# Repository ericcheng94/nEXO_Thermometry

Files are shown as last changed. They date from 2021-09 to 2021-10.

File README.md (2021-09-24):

# nNEXO_Microcontroller_Temp
Using Teensy 4.1 and Arduino Mega to collect temperatures using PT100's and thermocouples

Current TODO:
- Revise millis() timing system
- Fix NativeEthernet locking issue
- Prevent LCD burn in

Future feature adds:
- Utilize ILI9341 touch feature for interactive display

Schematic of PCB
thermo_schema

PCBnew
pcb

PCB Version 1  
https://oshpark.com/shared_projects/pfnhz9rr

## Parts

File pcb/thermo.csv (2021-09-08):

Reference | Quantity | Value | Footprint | Datasheet
0.1uF1 | 1 | C1 | Capacitor_THT:C_Disc_D3.0mm_W1.6mm_P2.50mm | Digikey BC1084CT-ND
ADC1 ADC2 ADC3 ADC4 ADC5 | 5 | PT100 | Thermometry:MAX31865
ADC6 | 1 | thermocouple1 | Thermometry:MAX31856
ADC7 | 1 | thermocouple2 | Thermometry:MAX31856
CP1 | 1 | 47uF | Capacitor_THT:CP_Radial_D5.0mm_P2.00mm | 2368-VHT47M25-ND
F1 | 1 | 1A | Thermometry:thermo_fuse | https://www.digikey.com/en/products/detail/littelfuse-inc/0154001-DRTL/2520456
ILI9341TFT1 ILI9341TFT2 | 2 | Conn_01x14 | Thermometry:ILI9341_2x7_connector | ~
ILI9341TFT3 | 1 | Conn_01x14 | Thermometry:ILI9341_1x14_connector | ~
J1 | 1 | DB15_Female | Thermometry:D15_Female_Horizontal | ~
J2 | 1 | Barrel_Jack | Connector_BarrelJack:BarrelJack_Horizontal | https://www.digikey.com/en/products/detail/cui-devices/PJ-002A/96962
MCU1 | 1 | Teensy4.1 | Thermometry:Teensy41
R1 R2 R3 R4 R5 R6 R7 R8 R9 R10 R11 R12 | 12 | 22 | Resistor_SMD:R_0805_2012Metric_Pad1.20x1.40mm_HandSolder | ~
R13 | 1 | 0 | Resistor_SMD:R_0805_2012Metric_Pad1.20x1.40mm_HandSolder | ~
Teensy_Ethernet1 | 1 | RJ45_LED | Connector_RJ:RJ45_Cetus_J1B1211CCD_Horizontal | ~
U1 | 1 | BME280 | Thermometry:BME280

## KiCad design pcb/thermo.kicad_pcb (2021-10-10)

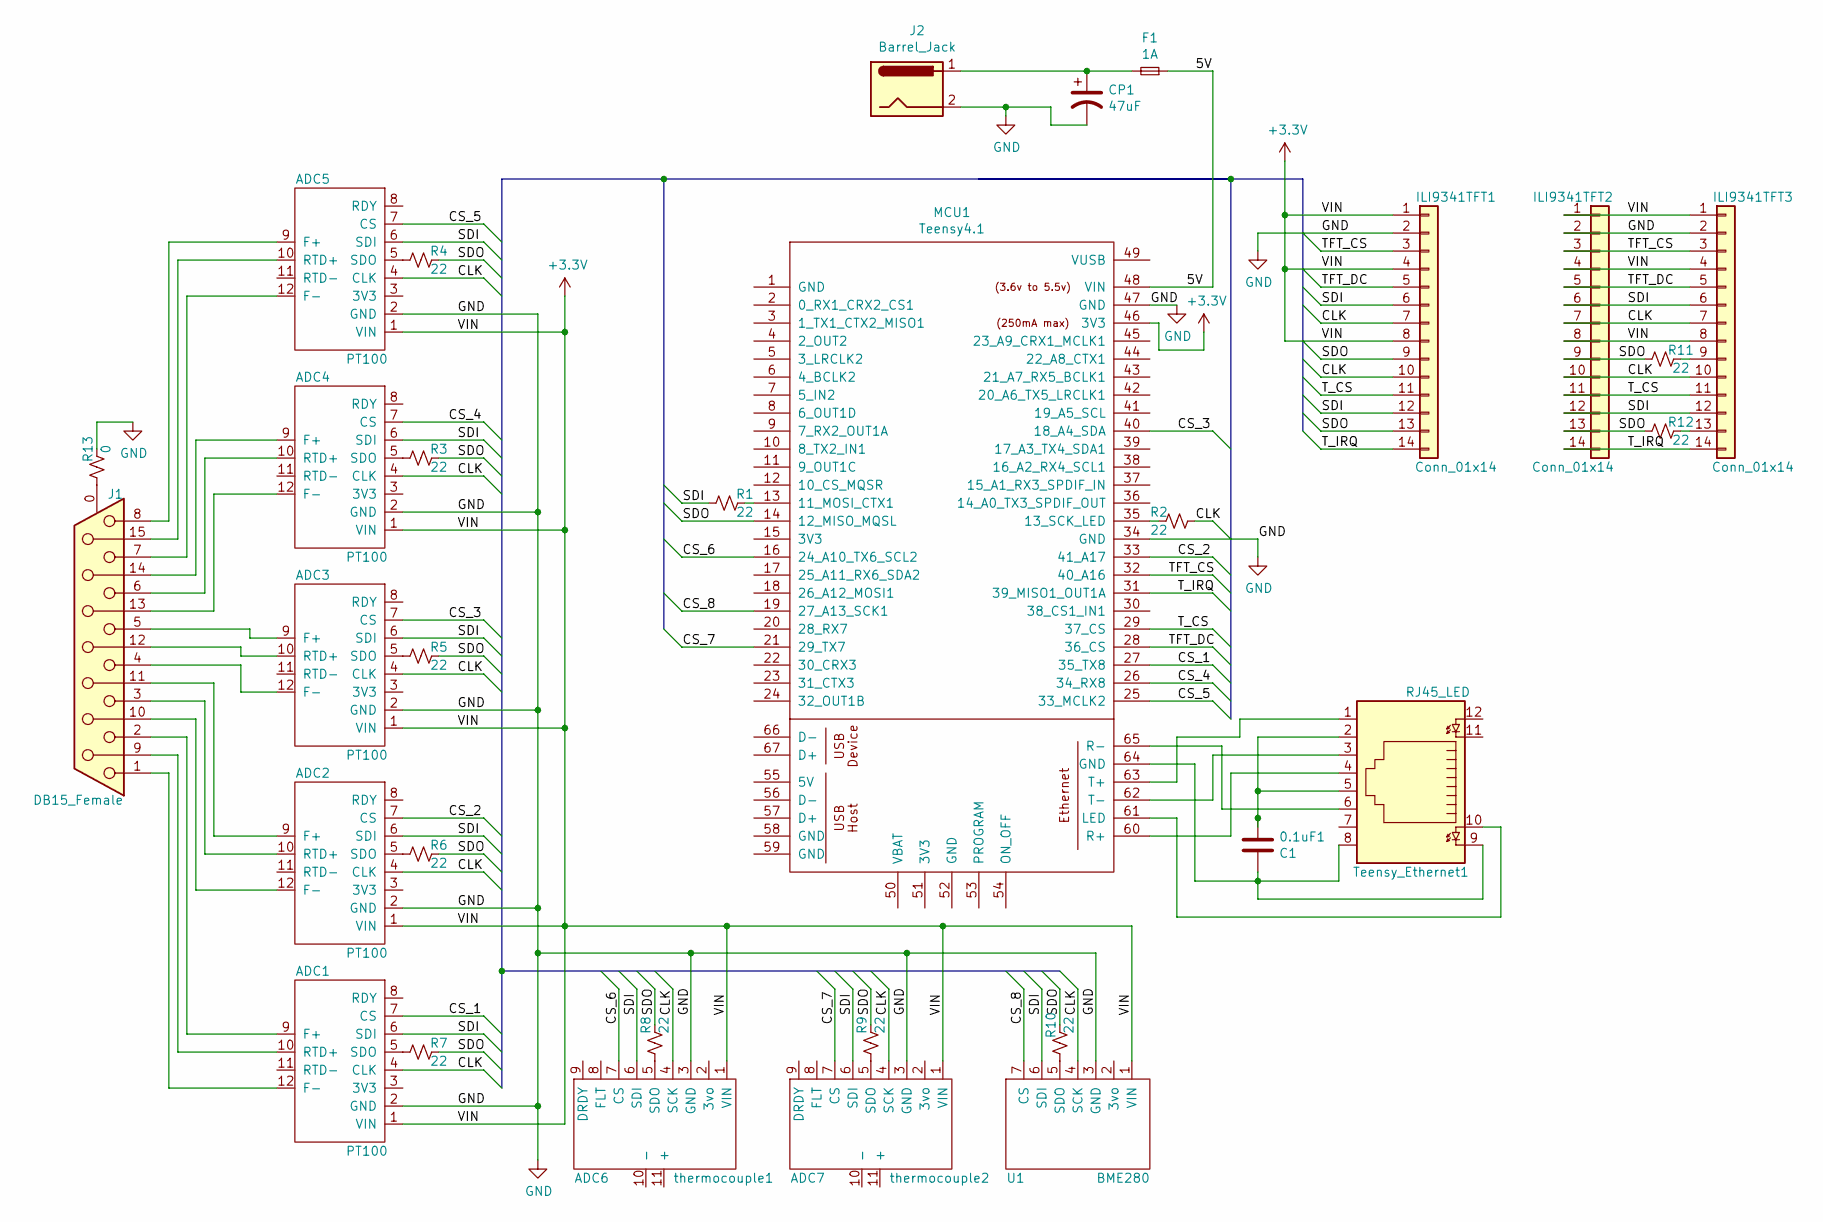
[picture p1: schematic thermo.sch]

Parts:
0.1uF1: C1; C_Disc_D3.0mm_W1.6mm_P2.50mm
ADC1, ADC2, ADC3, ADC4, ADC5: PT100; MAX31865
ADC6: thermocouple1; MAX31856
ADC7: thermocouple2; MAX31856
CP1: 47uF; CP_Radial_D5.0mm_P2.00mm
F1: 1A; thermo_fuse
ILI9341TFT1, ILI9341TFT2: Conn_01x14; ILI9341_2x7_connector
ILI9341TFT3: Conn_01x14; ILI9341_1x14_connector
J1: DB15_Female; D15_Female_Horizontal
J2: Barrel_Jack; BarrelJack_Horizontal
MCU1: Teensy4.1; Teensy41
R1, R2, R3, R4, R5, R6, R7, R8, R9, R10, R11, R12: 22; R_0805_2012Metric_Pad1.20x1.40mm_HandSolder
R13: 0; R_0805_2012Metric_Pad1.20x1.40mm_HandSolder
Teensy_Ethernet1: RJ45_LED; RJ45_Cetus_J1B1211CCD_Horizontal
U1: BME280

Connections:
+3V3: ADC1.1 (VIN), ADC2.1 (VIN), ADC3.1 (VIN), ADC4.1 (VIN), ADC5.1 (VIN), ADC6.1 (VIN), ADC7.1 (VIN), ILI9341TFT1.1, ILI9341TFT1.4, ILI9341TFT1.8, ILI9341TFT2.1, ILI9341TFT2.4, ILI9341TFT2.8, ILI9341TFT3.1, ILI9341TFT3.4, ILI9341TFT3.8, MCU1.46 (3V3), U1.1 (VIN)
/5V: F1.1, MCU1.48 (VIN)
/CLK: ADC1.4 (CLK), ADC2.4 (CLK), ADC3.4 (CLK), ADC4.4 (CLK), ADC5.4 (CLK), ADC6.4 (SCK), ADC7.4 (SCK), ILI9341TFT1.7, ILI9341TFT1.10, ILI9341TFT2.7, ILI9341TFT2.10, ILI9341TFT3.7, ILI9341TFT3.10, R2.1, U1.4 (SCK)
/CS_1: ADC1.7 (CS), MCU1.27 (35_TX8)
/CS_2: ADC2.7 (CS), MCU1.33 (41_A17)
/CS_3: ADC3.7 (CS), MCU1.40 (18_A4_SDA)
/CS_4: ADC4.7 (CS), MCU1.26 (34_RX8)
/CS_5: ADC5.7 (CS), MCU1.25 (33_MCLK2)
/CS_6: ADC6.7 (CS), MCU1.16 (24_A10_TX6_SCL2)
/CS_7: ADC7.7 (CS), MCU1.21 (29_TX7)
/CS_8: MCU1.19 (27_A13_SCK1), U1.7 (CS)
/SDI: ADC1.6 (SDI), ADC2.6 (SDI), ADC3.6 (SDI), ADC4.6 (SDI), ADC5.6 (SDI), ADC6.6 (SDI), ADC7.6 (SDI), ILI9341TFT1.6, ILI9341TFT1.12, ILI9341TFT2.6, ILI9341TFT2.12, ILI9341TFT3.6, ILI9341TFT3.12, R1.2, U1.6 (SDI)
/SDO: ILI9341TFT1.9, ILI9341TFT1.13, ILI9341TFT2.9, ILI9341TFT2.13, MCU1.14 (12_MISO_MQSL), R3.1, R4.1, R5.1, R6.1, R7.1, R8.1, R9.1, R10.1, R11.2, R12.2
/TFT_CS: ILI9341TFT1.3, ILI9341TFT2.3, ILI9341TFT3.3, MCU1.32 (40_A16)
/TFT_DC: ILI9341TFT1.5, ILI9341TFT2.5, ILI9341TFT3.5, MCU1.28 (36_CS)
/T_CS: ILI9341TFT1.11, ILI9341TFT2.11, ILI9341TFT3.11, MCU1.29 (37_CS)
/T_IRQ: ILI9341TFT1.14, ILI9341TFT2.14, ILI9341TFT3.14, MCU1.31 (39_MISO1_OUT1A)
GND: ADC1.2 (GND), ADC2.2 (GND), ADC3.2 (GND), ADC4.2 (GND), ADC5.2 (GND), ADC6.3 (GND), ADC7.3 (GND), CP1.2, ILI9341TFT1.2, ILI9341TFT2.2, ILI9341TFT3.2, J2.2, MCU1.34 (GND), MCU1.47 (GND), R13.1, U1.3 (GND)
unnamed: 0.1uF1.1, Teensy_Ethernet1.2, Teensy_Ethernet1.5
unnamed: 0.1uF1.2, MCU1.64 (GND), Teensy_Ethernet1.8, Teensy_Ethernet1.9
unnamed: ADC1.5 (SDO), R7.2
unnamed: ADC1.9 (F+), J1.2
unnamed: ADC1.10 (RTD+), J1.9
unnamed: ADC1.12 (F-), J1.1
unnamed: ADC2.5 (SDO), R6.2
unnamed: ADC2.9 (F+), J1.11 (P111)
unnamed: ADC2.10 (RTD+), J1.3
unnamed: ADC2.12 (F-), J1.10
unnamed: ADC3.5 (SDO), R5.2
unnamed: ADC3.9 (F+), J1.5
unnamed: ADC3.10 (RTD+), J1.12
unnamed: ADC3.12 (F-), J1.4
unnamed: ADC4.5 (SDO), R3.2
unnamed: ADC4.9 (F+), J1.14
unnamed: ADC4.10 (RTD+), J1.6
unnamed: ADC4.12 (F-), J1.13
unnamed: ADC5.5 (SDO), R4.2
unnamed: ADC5.9 (F+), J1.8
unnamed: ADC5.10 (RTD+), J1.15
unnamed: ADC5.12 (F-), J1.7
unnamed: ADC6.5 (SDO), R8.2
unnamed: ADC7.5 (SDO), R9.2
unnamed: CP1.1, F1.2, J2.1
unnamed: ILI9341TFT3.9, R11.1
unnamed: ILI9341TFT3.13, R12.1
unnamed: J1.0 (PAD), R13.2
unnamed: MCU1.13 (11_MOSI_CTX1), R1.1
unnamed: MCU1.35 (13_SCK_LED), R2.2
unnamed: MCU1.60 (R+), Teensy_Ethernet1.4
unnamed: MCU1.61 (LED), Teensy_Ethernet1.10
unnamed: MCU1.62 (T-), Teensy_Ethernet1.3
unnamed: MCU1.63 (T+), Teensy_Ethernet1.1
unnamed: MCU1.65 (R-), Teensy_Ethernet1.6
unnamed: R10.2, U1.5 (SDO)

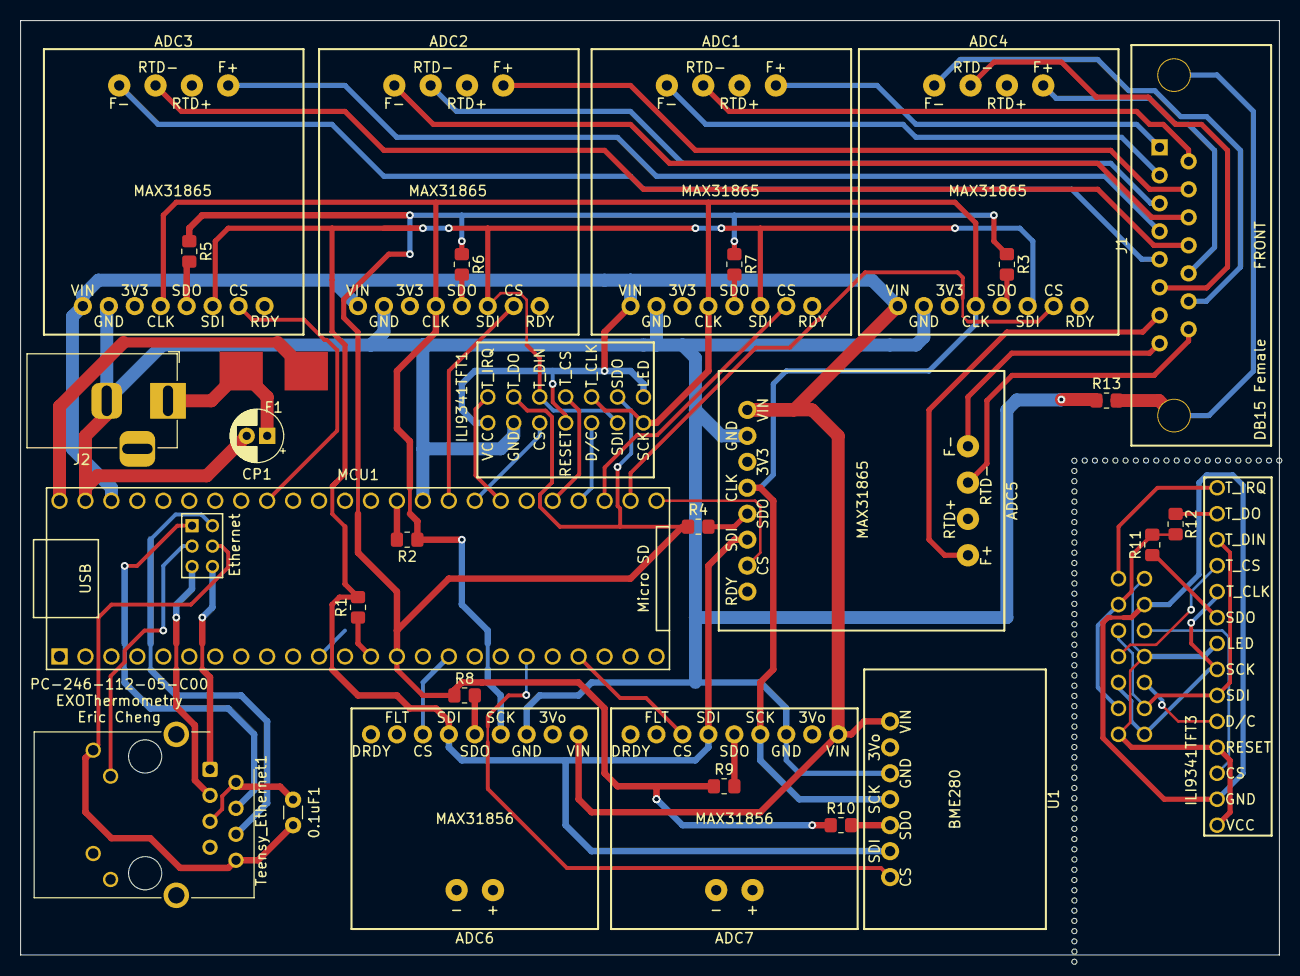
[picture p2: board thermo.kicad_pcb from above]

Board: 2 copper layers, 123.2 x 91.4 mm, 31 parts (1 on the bottom side), 54 nets.

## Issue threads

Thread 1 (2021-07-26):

Ambiguous declare

bungernut, 2021-07-26:
https://github.com/ericcheng94/nNEXO_Microcontroller_Temp/blob/5b1cc3159d358c7eaec6f1060fe57ec7ec3c33e6/nEXO_Teensy.ino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

you should use uint32_t to remove any ambiguity in size. It may not be an issue in the Arduino environment but it's a good habit to use them since different compilers could have different lengths. Also less typing so win-win.

Closed 2021-09-10.

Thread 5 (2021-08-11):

NativeEthernet.begin is locking

bungernut, 2021-08-11:
It turns out that begin method in NativeEthernet is going to hang the system if no ethernet cable is connected.
https://github.com/vjmuzik/NativeEthernet/blob/fe82aa7cab344760346bda5d0da031a4adeff2e2/src/NativeEthernet.cpp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

No obvious fix exists as far as I know, but it's discussed here:
https://forum.pjrc.com/threads/65653-non-blocking-Ethernet-begin()-with-cable-disconnected-amp-static-IP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

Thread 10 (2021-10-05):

RTD+ and RTD- got reversed from SCH to PCB

bungernut, 2021-10-05:
The 3 wire RTD should connect to RTD+ F+ and F-, this was correct on the SCH, but it is wrong on the PCB.

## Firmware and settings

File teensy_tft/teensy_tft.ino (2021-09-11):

#include <Adafruit_MAX31865.h>
#include <Adafruit_MAX31856.h>
#include <Adafruit_BME280.h>
#include <Wire.h>
#include <SPI.h>
#include "ILI9341_t3.h"
#include <NativeEthernet.h>
#include <Arduino.h>
#include <ArduinoRS485.h> // ArduinoModbus depends on the ArduinoRS485 library
#include <ArduinoModbus.h>

Adafruit_MAX31865 rtd01 = Adafruit_MAX31865(35);
Adafruit_MAX31865 rtd02 = Adafruit_MAX31865(41);
// Adafruit_MAX31865 rtd03 = Adafruit_MAX31865(18);
// Adafruit_MAX31865 rtd04 = Adafruit_MAX31865(34);
// Adafruit_MAX31865 rtd05 = Adafruit_MAX31865(33);
Adafruit_MAX31856 tcp01 = Adafruit_MAX31856(24);
// Adafruit_MAX31856 tcp02 = Adafruit_MAX31856(29);
Adafruit_BME280 bme(27); // hardware SPI

#define VERSION "nEXO Thermometry v1.1"
#define TFT_DC 36
#define TFT_CS 40
#define T_CS 37
#define T_IRQ 39
ILI9341_t3 tft = ILI9341_t3(TFT_CS, TFT_DC);

// The value of the Rref resistor. Use 430.0 for PT100 and 4300.0 for PT1000
#define RREF      430.0
// The 'nominal' 0-degrees-C resistance of the sensor
// 100.0 for PT100, 1000.0 for PT1000
#define RNOMINAL  100.0

// Enter a MAC address for your controller below.
byte mac[] = {0xDE, 0xAD, 0xBE, 0xEF, 0xFE, 0xED};
// The IP address will be dependent on your local network:
IPAddress ip(192, 168, 0, 242);

EthernetServer ethServer(502);
ModbusTCPServer modbusTCPServer;

uint32_t currentMillis;
uint32_t pollModbusMillis;
uint32_t updateSensorsMillis;
uint32_t updateClientMillis;
uint32_t updateSerialMillis;
uint32_t updateDisplayMillis;
// unsigned int  heartbeat;

// Global variables to make current sensor temps available to every function
float rtd01temp;
float rtd02temp;
float rtd03temp;
float rtd04temp;
float rtd05temp;
float tcp01temp;
float tcp02temp;
float bmeTemp;

//Modbus holding register address mapping
const int rtd01_reg = 0x00;
const int rtd02_reg = 0x01;
const int rtd03_reg = 0x02;
const int rtd04_reg = 0x03;
const int rtd05_reg = 0x04;
const int tcp01_reg1 = 0x05;
const int tcp01_reg2 = 0x06;
const int tcp02_reg1 = 0x07;
const int tcp02_reg2 = 0x08;
const int bme_reg1 = 0x09;
const int bme_reg2 = 0x010;
// const int tick_tock = 0x11;

void setup() {
  Serial.begin(115200);
//  while (!Serial) {
//    ; // wait for serial port to connect. Needed for native USB port only
//  }
  Serial.println(VERSION);
  rtd01.begin(MAX31865_3WIRE);  // set to 2WIRE or 4WIRE as necessary
  rtd02.begin(MAX31865_3WIRE);  // set to 2WIRE or 4WIRE as necessary
//  rtd03.begin(MAX31865_3WIRE);  // set to 2WIRE or 4WIRE as necessary
//  rtd04.begin(MAX31865_3WIRE);  // set to 2WIRE or 4WIRE as necessary
//  rtd05.begin(MAX31865_3WIRE);  // set to 2WIRE or 4WIRE as necessary
  tcp01.begin();
  tcp01.setThermocoupleType(MAX31856_TCTYPE_T);
//  tcp02.begin();
//  tcp02.setThermocoupleType(MAX31856_TCTYPE_T);
  tft.begin();

  Ethernet.begin(mac, ip);
  // Check for Ethernet hardware present
  if (Ethernet.hardwareStatus() == EthernetNoHardware) {
    Serial.println("Ethernet shield was not found.  Sorry, can't run without hardware. :(");
    while (true) {
      delay(1); // do nothing, no point running without Ethernet hardware
    }
  }
  // Keeps displaying error despite having thernet connection, commented out for now
  // if (Ethernet.linkStatus() == LinkOFF) {
  //   Serial.println("Ethernet cable is not connected.");
  // }

  // Start the server
  ethServer.begin();

  // start the Modbus TCP server
  if (!modbusTCPServer.begin()) {
    Serial.println("Failed to start Modbus TCP Server!");
    while (1);
  }

  // initialize BME280 sensor
  bme.begin();
//  if (!bme.begin()) {
//    Serial.println("Could not find a valid BME280 sensor, check wiring!");
//    while (1);
//  }

  // configure 12 holding registers at address 0x00
  modbusTCPServer.configureHoldingRegisters(0x00, 12);

  // Setup ILI9341 TFT LCD
  tft.fillScreen(ILI9341_BLACK);
  tft.setTextColor(ILI9341_WHITE);
  tft.setTextSize(3);
  tft.setRotation(3);
  tft.setCursor(10, 10);
  tft.println(VERSION);
  tft.fillScreen(ILI9341_BLACK);
}

void loop() {
  EthernetClient client = ethServer.available();
  // listen for incoming clients
  if (client) {
    Serial.println("Client Connected");
    modbusTCPServer.accept(client);

    while (client.connected()) {
      currentMillis = millis();

      if (currentMillis - pollModbusMillis > 1000) {
        // poll for Modbus TCP requests, while client connected
        modbusTCPServer.poll();
        pollModbusMillis = currentMillis;

//         if (heartbeat > 65000) {
//           heartbeat = 1;
//         } else if (heartbeat % 2 == 1) {
//           modbusTCPServer.holdingRegisterWrite(tick_tock, 1);
//           heartbeat = 0;
//         } else {
//           modbusTCPServer.holdingRegisterWrite(tick_tock, 0);
//           heartbeat = 1;
//         }
      }

      if (currentMillis - updateSensorsMillis > 250) {
        rtd01temp = rtd01.temperature(RNOMINAL, RREF);
        rtd02temp = rtd02.temperature(RNOMINAL, RREF);
//        rtd03temp = rtd03.temperature(RNOMINAL, RREF);
//        rtd04temp = rtd04.temperature(RNOMINAL, RREF);
//        rtd05temp = rtd05.temperature(RNOMINAL, RREF);
        tcp01temp = tcp01.readThermocoupleTemperature();
//        tcp02temp = tcp02.readThermocoupleTemperature();
        bmeTemp = bme.readTemperature();

        // Change Celsius to Kelvin
        rtd01temp += 273.15;
        rtd02temp += 273.15;
        rtd03temp += 273.15;
        rtd04temp += 273.15;
        rtd05temp += 273.15;
        tcp01temp += 273.15;
        tcp02temp += 273.15;
        bmeTemp += 273.15;

        updateSensorsMillis = currentMillis;
      }

      if (currentMillis - updateClientMillis > 1000) {
        updateClient(tcp01temp, bmeTemp);
//        updateClient(tcp01temp, tcp02temp);
        updateClientMillis = currentMillis;
      }

      if (currentMillis - updateSerialMillis > 2000) {
        updateSerial(rtd01temp, rtd02temp, tcp01temp, bmeTemp);
//        updateSerial(rtd01temp, rtd02temp, rtd03temp, rtd04temp, rtd05temp, tcp01temp, tcp02temp, bmeTemp);
        updateSerialMillis = currentMillis;
      }

      if (currentMillis - updateDisplayMillis > 1000) {
        updateDisplay(rtd01temp, rtd02temp, tcp01temp, bmeTemp);
//        updateDisplay(rtd01temp, rtd02temp, rtd03temp, rtd04temp, rtd05temp, tcp01temp, tcp02temp, bmeTemp);
        updateDisplayMillis = currentMillis;
      }
    }
  }
  // backup for if client disconnects, display still runs
  rtd01temp = rtd01.temperature(RNOMINAL, RREF);
  rtd02temp = rtd02.temperature(RNOMINAL, RREF);
//  rtd03temp = rtd03.temperature(RNOMINAL, RREF);
//  rtd04temp = rtd04.temperature(RNOMINAL, RREF);
//  rtd05temp = rtd05.temperature(RNOMINAL, RREF);
  tcp01temp = tcp01.readThermocoupleTemperature();
//  tcp02temp = tcp02.readThermocoupleTemperature();
  bmeTemp = bme.readTemperature();

  // Change Celsius to Kelvin
  rtd01temp += 273.15;
  rtd02temp += 273.15;
  rtd03temp += 273.15;
  rtd04temp += 273.15;
  rtd05temp += 273.15;
  tcp01temp += 273.15;
  tcp02temp += 273.15;
  bmeTemp += 273.15;

  updateDisplay(rtd01temp, rtd02temp, tcp01temp, bmeTemp);
//  updateDisplay(rtd01temp, rtd02temp, rtd03temp, rtd04temp, rtd05temp, tcp01temp, tcp02temp, bmeTemp);
  delay(250); // TODO Change to millis
}

union {
    float asFloat;
    uint16_t asInt[2];
} flreg;

void updateClient(float tcp01temp, float bmeTemp) {
  uint16_t rawRTD01 = rtd01.readRTD();
  uint16_t rawRTD02 = rtd02.readRTD();
//  uint16_t rawRTD03 = rtd03.readRTD();
//  uint16_t rawRTD04 = rtd04.readRTD();
//  uint16_t rawRTD05 = rtd05.readRTD();
  modbusTCPServer.holdingRegisterWrite(rtd01_reg, rawRTD01);
  modbusTCPServer.holdingRegisterWrite(rtd02_reg, rawRTD02);
//  modbusTCPServer.holdingRegisterWrite(rtd03_reg, rawRTD03);
//  modbusTCPServer.holdingRegisterWrite(rtd04_reg, rawRTD04);
//  modbusTCPServer.holdingRegisterWrite(rtd05_reg, rawRTD05);

  flreg.asFloat = tcp01temp;
  modbusTCPServer.holdingRegisterWrite(tcp01_reg1, flreg.asInt[1]);
  modbusTCPServer.holdingRegisterWrite(tcp01_reg2, flreg.asInt[0]);
//  flreg.asFloat = tcp02temp;
//  modbusTCPServer.holdingRegisterWrite(tcp02_reg1, flreg.asInt[1]);
//  modbusTCPServer.holdingRegisterWrite(tcp02_reg2, flreg.asInt[0]);
  flreg.asFloat = bmeTemp;
  modbusTCPServer.holdingRegisterWrite(bme_reg1, flreg.asInt[1]);
  modbusTCPServer.holdingRegisterWrite(bme_reg2, flreg.asInt[0]);
}

void  updateSerial(float rtd01temp, float rtd02temp, float tcp01temp, float bmeTemp) {
//  uint16_t rtd = rtd01.readRTD();
//  Serial.print("RTD value: "); Serial.println(rtd);
//  float ratio = rtd;
//  ratio /= 32768;
//  Serial.print("Ratio = "); Serial.println(ratio,8);
//  Serial.print("Resistance = "); Serial.println(RREF*ratio,8);
  Serial.print("RTD01 temperature : "); Serial.println(rtd01temp);
  Serial.print("RTD02 temperature : "); Serial.println(rtd02temp);
//  Serial.print("RTD03 temperature : "); Serial.println(rtd03temp);
//  Serial.print("RTD04 temperature : "); Serial.println(rtd04temp);
//  Serial.print("RTD05 temperature : "); Serial.println(rtd05temp);
  Serial.print("TC01 Temperature:   "); Serial.println(tcp01temp);
//  Serial.print("TC02 Temperature:     "); Serial.println(tcp02temp);
//  Serial.print("TC Cold Junction:   "); Serial.println(tcp01.readCJTemperature());
  Serial.print("BME280 Temperature: "); Serial.println(bmeTemp);
  Serial.println();
}

void updateDisplay(float rtd01temp, float rtd02temp, float tcp01temp, float bmeTemp) {
  tft.setTextSize(3);
  tft.setTextColor(ILI9341_WHITE, ILI9341_BLACK);
  tft.setCursor(10, 10);
  tft.print("RTD_01:"); tft.print(rtd01temp); tft.println(" K");
  tft.setCursor(10, 40);
  tft.print("RTD_02:"); tft.print(rtd02temp); tft.println(" K");
  tft.setCursor(10, 70);
  tft.print("RTD_03:"); tft.print("--"); tft.println(" K");
  tft.setCursor(10, 100);
  tft.print("RTD_04:"); tft.print("--"); tft.println(" K");
  tft.setCursor(10, 130);
  tft.print("RTD_05:"); tft.print("--"); tft.println(" K");

  tft.setTextColor(ILI9341_YELLOW, ILI9341_BLACK);
  tft.setCursor(10, 160);
  tft.print("TCP_01:"); tft.print(tcp01temp); tft.println(" K");
  tft.setCursor(10, 190);
  tft.print("TCP_02:"); tft.print("--"); tft.println(" K");

  tft.setTextColor(ILI9341_WHITE, ILI9341_BLACK);
  tft.setCursor(10, 220);
  tft.setTextSize(2);
  tft.print("BME_280:"); tft.print(bmeTemp); tft.println(" K");
}

void checkPTFault() {
  // Check and print any faults
  uint8_t fault = rtd01.readFault();
  if (fault) {
    Serial.print("Fault 0x"); Serial.println(fault, HEX);
    if (fault & MAX31865_FAULT_HIGHTHRESH) {
      Serial.println("RTD High Threshold");
    }
    if (fault & MAX31865_FAULT_LOWTHRESH) {
      Serial.println("RTD Low Threshold");
    }
    if (fault & MAX31865_FAULT_REFINLOW) {
      Serial.println("REFIN- > 0.85 x Bias");
    }
    if (fault & MAX31865_FAULT_REFINHIGH) {
      Serial.println("REFIN- < 0.85 x Bias - FORCE- open");
    }
    if (fault & MAX31865_FAULT_RTDINLOW) {
      Serial.println("RTDIN- < 0.85 x Bias - FORCE- open");
    }
    if (fault & MAX31865_FAULT_OVUV) {
      Serial.println("Under/Over voltage");
    }
    rtd01.clearFault();
  }
}

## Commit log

2021-07-23 Add files via upload
    After showing the temperature once, everything freezes, until I reset it manually. On the Mega it just auto resets the board
2021-08-09 Chat with Brian before review
    [thermo.sch]
2021-08-09 Add files via upload
    Ready for review
    [MAX31865.sch, thermo.sch]
2021-08-19 Pre-adding traces
    [thermo.kicad_pcb, thermo.sch]
2021-08-20 Latest upload for Brian to check
    [thermo.kicad_pcb, thermo.sch]
2021-08-20 Revised latest for Brian to check
    [thermo.kicad_pcb]
2021-09-02 Updated to latest specs
    [thermo.kicad_pcb, thermo.sch]
2021-09-08 removed acid trap and made some tracer wider
    [thermo.kicad_pcb]
2021-09-08 generated BOM CSVs
    [thermo.csv]
2021-09-10 revised pins for all SPI devices to match printed pcb
2021-09-10 cleaned up serial monitor to accept future sensors, some code cleanup
2021-09-11 sending bme280 float as modbus registers, fixed display kelvin bug, added additional kelvin conversions
    [teensy_tft.ino]
2021-09-24 Update README.md
    Adding OSHpark link for the version 1 of the board incase someone finds the project here
2021-10-10 added missing SDI trace for ADC1
    [thermo.kicad_pcb]
